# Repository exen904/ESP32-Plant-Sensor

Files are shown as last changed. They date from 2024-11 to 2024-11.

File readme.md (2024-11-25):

# ESP-32 Plant Sensor for ESP-Home and HomeAssistant

This is a simple PCB to attach 6 capacitive moisuture sensors to a ESP32 for plant monitoring in HomeAssistant. The available MiFlora and Tuya clones with Zigbee were to expensive to purchase for all of my plants, so I chose this way. 

The PCB works with both V1.2 and V2.0 sensors and applys 5V as working voltage to make it compatible with either one. Connection to the sensors is made via JST 2.0 connectors. 

## Update
PCB has been updated to accomodate larger tolerances on the ESP footprint THT holes. My first protoytpe showed no errors, but I could confirm, that the tolerances on the THT holes are extremely tight. I adjusted this in the current version, so if you did not order PCBs, please use the current version. If you ordered PCBs from the first revision, you can take a chance at drilling the holes up but I dont really recommend that, as you can also break traces during that. 

## ESP Pinout
Please refer to my KiCad Footprint of the ESP I used for the pinout, as there are so many different ESP Devkits available. 

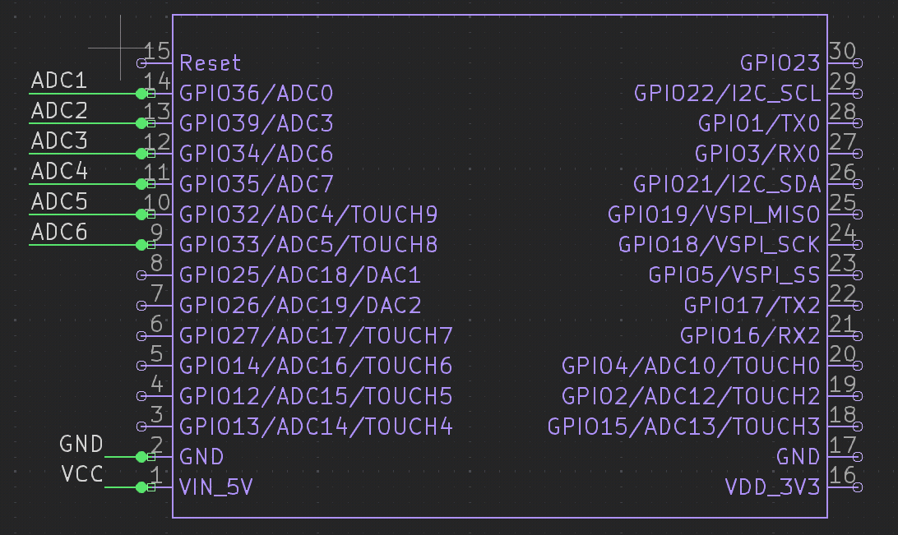
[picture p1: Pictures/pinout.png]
Pinout


## BOM
- 1x ESP32 Devkit with the correct pinout
- 6x JST B3B-XH-A (2.0mm vertical) connectors
- 4x M2x4 screws for securing the PCB in the bottom case

## Software
I run these with ESPHome, see my code in the code folder. Calibrate the values under `calibrate_linear` for each state of sensor dry and sensor 100% (sensor partly emerged underwater).

For the HomeAssistant side of things, I created a configuration.yaml entry, which ties each sensor to a plant entity. Example also linked in the code folder. Please do yourself a favour, and name your sensors in ESPHome better than I did.

## Pictures
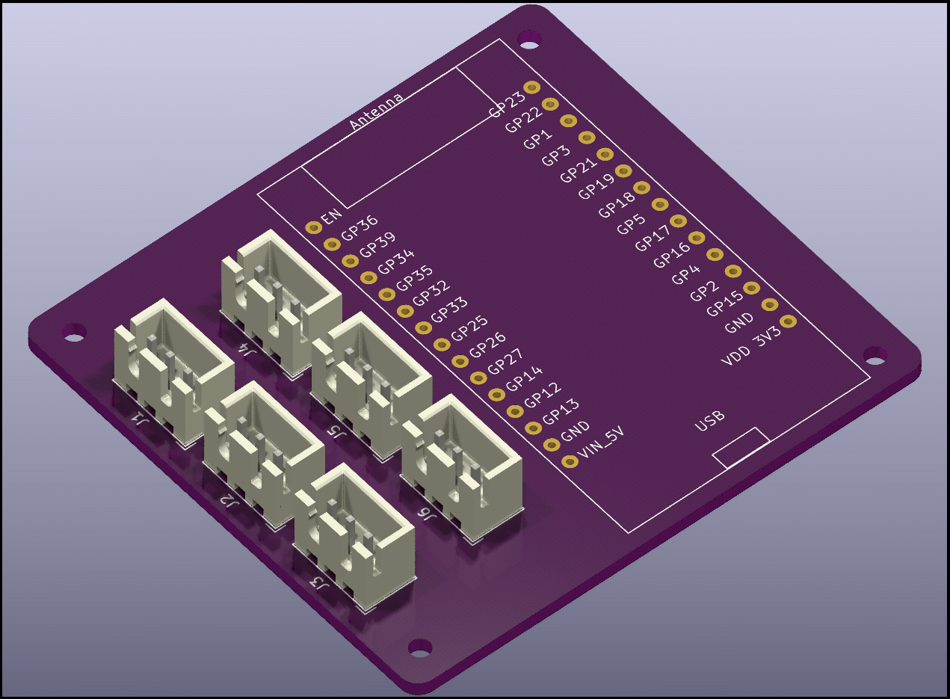
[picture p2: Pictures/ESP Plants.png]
PCB render

soldered PCB

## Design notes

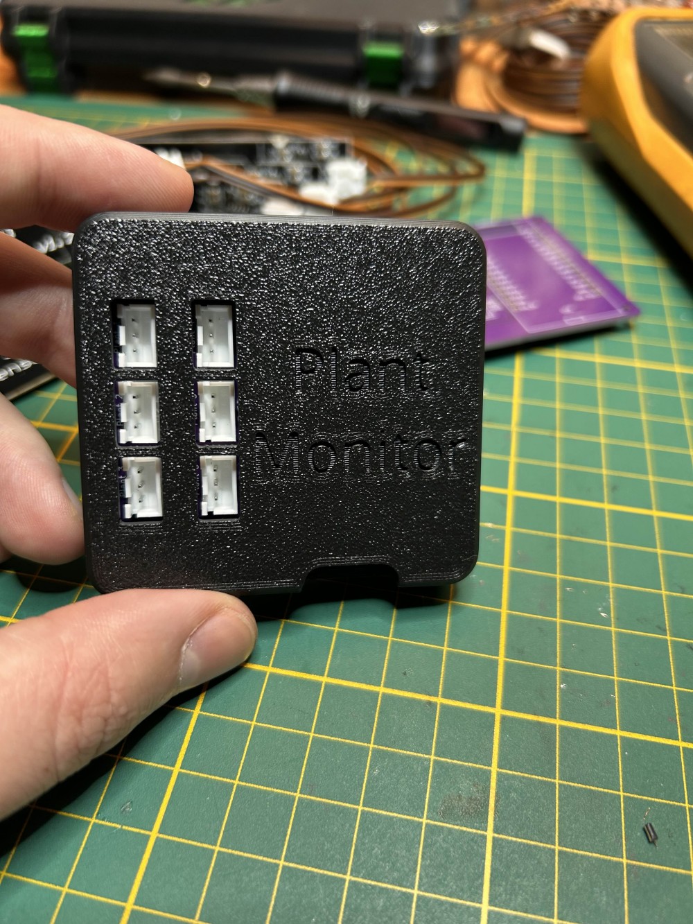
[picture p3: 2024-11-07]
Pictures/plant1.jpg

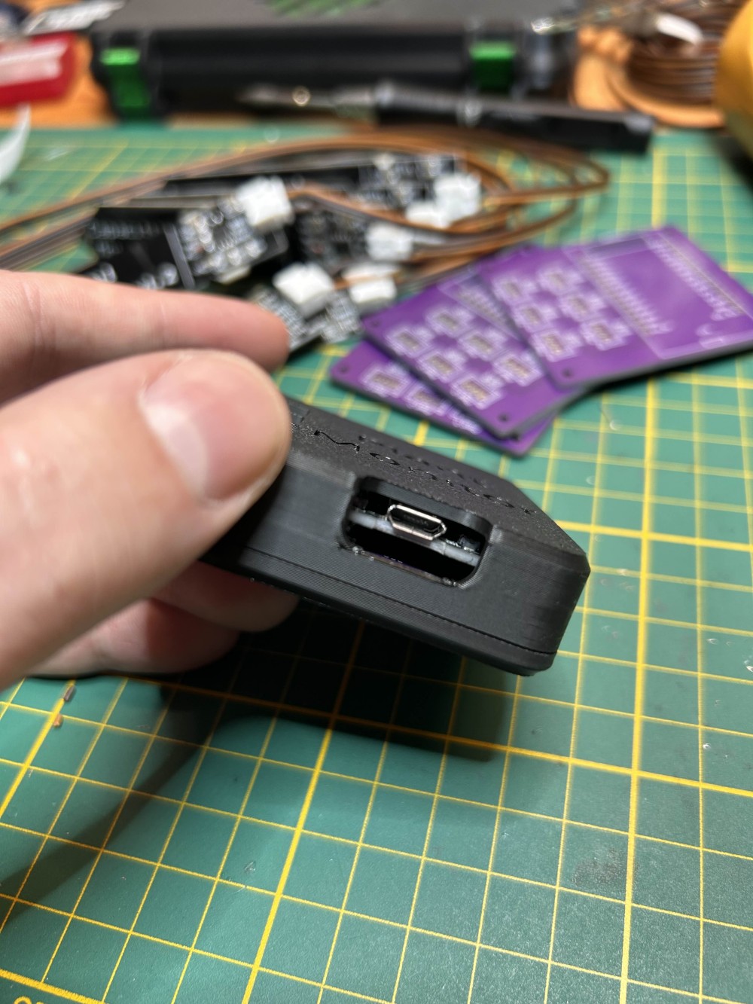
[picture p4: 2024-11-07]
Pictures/plant2.jpg

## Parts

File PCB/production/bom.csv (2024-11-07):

Designator | Footprint | Quantity | Value | LCSC Part #
NODEMCU_32S1 | ESP32_NodeMCU | 1 | ~
PLANT 1, PLANT 2, PLANT 3, PLANT 4, PLANT 5, PLANT 6 | JST_XH_B3B-XH-A_1x03_P2.50mm_Vertical | 6 | Conn_01x03_Pin

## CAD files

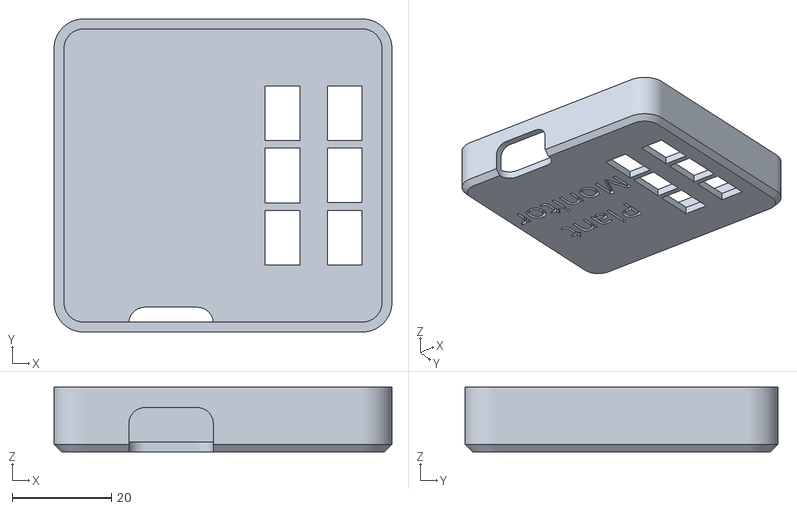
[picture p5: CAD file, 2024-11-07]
Case/Top_with_text.stl
68.0 x 63.0 x 13.0

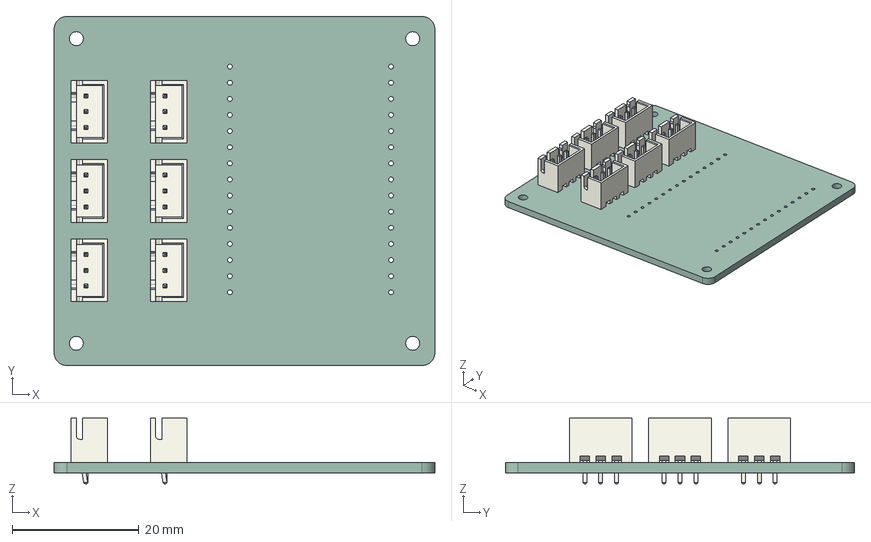
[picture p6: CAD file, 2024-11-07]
PCB/ESP Plants.step
60.0 x 55.0 x 10.4 mm
JST_B3B_XH_A x 6
_autosave-ESP Plants_PCB

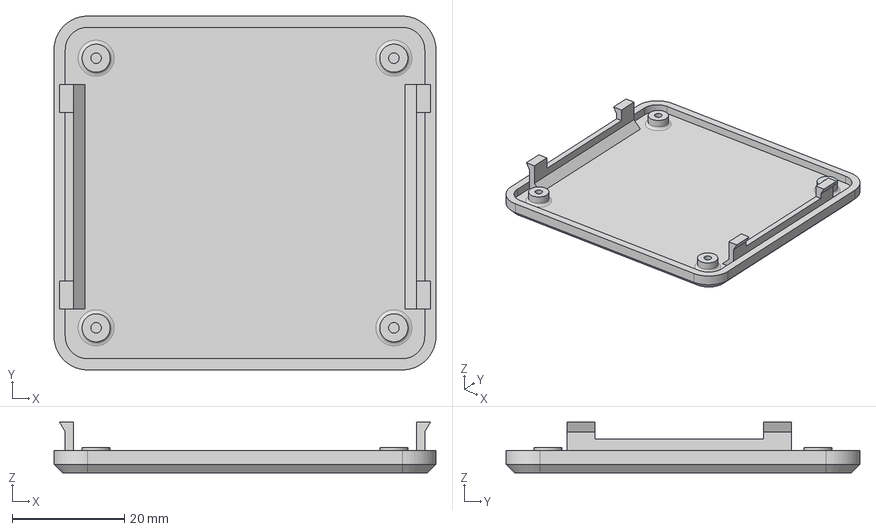
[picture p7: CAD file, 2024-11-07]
Case/Bottom.step
68.0 x 63.0 x 9.00 mm

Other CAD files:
Case/Top.step

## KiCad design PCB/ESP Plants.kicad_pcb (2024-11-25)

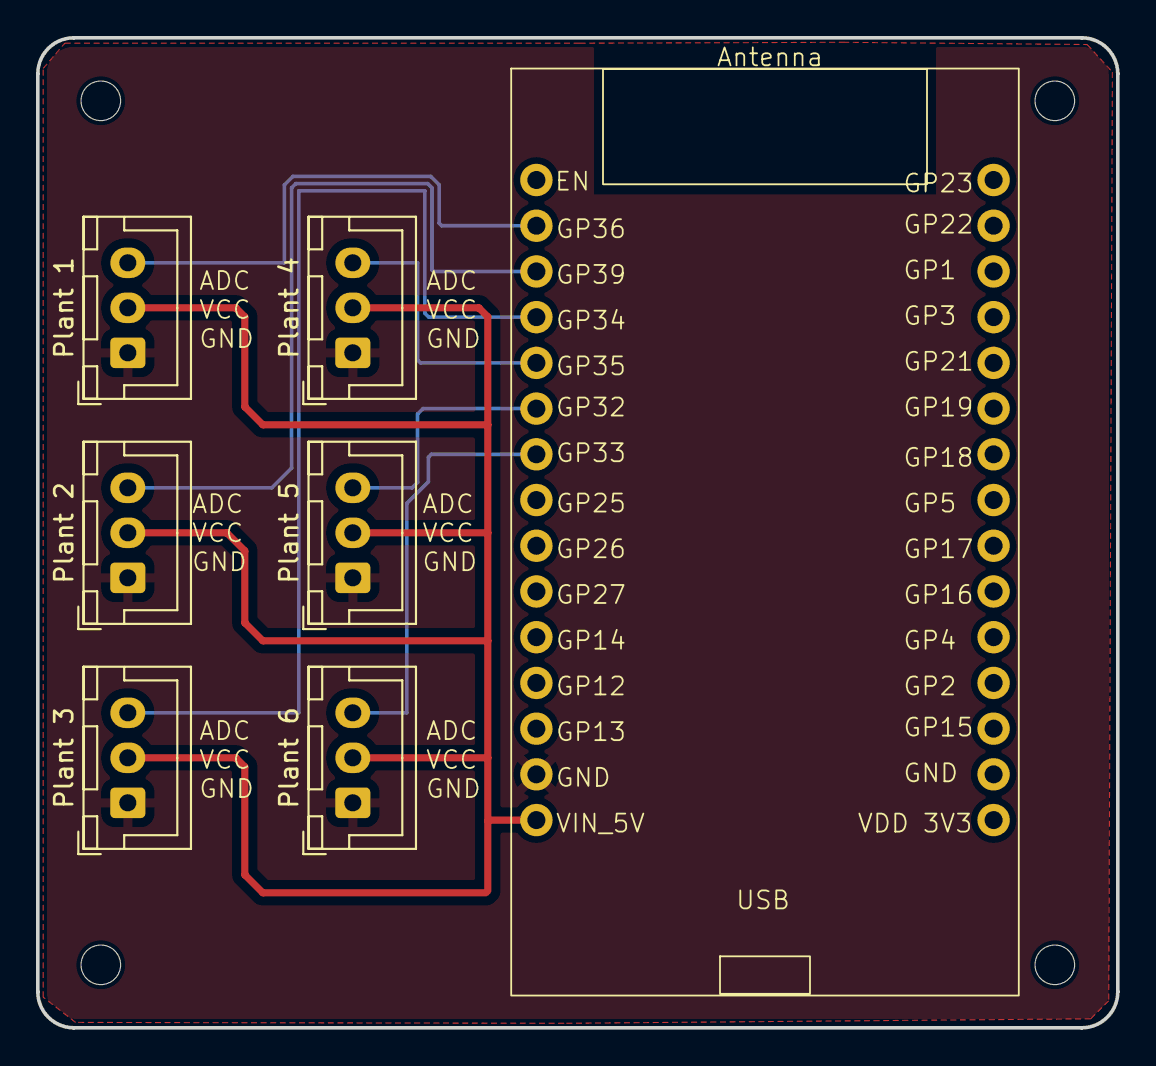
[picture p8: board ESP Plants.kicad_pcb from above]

Board: 2 copper layers, 60.0 x 55.0 mm, 7 parts (0 on the bottom side), 8 nets.

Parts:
NodeMCU_32S1: ESP32_NodeMCU
Plant 1, Plant 2, Plant 3, Plant 4, Plant 5, Plant 6: Conn_01x03_Pin; JST_XH_B3B-XH-A_1x03_P2.50mm_Vertical

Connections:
/ADC1: NodeMCU_32S1.14 (GPIO36/ADC0), Plant 1.3
/ADC2: NodeMCU_32S1.13 (GPIO39/ADC3), Plant 2.3
/ADC3: NodeMCU_32S1.12 (GPIO34/ADC6), Plant 3.3
/ADC4: NodeMCU_32S1.11 (GPIO35/ADC7), Plant 4.3
/ADC5: NodeMCU_32S1.10 (GPIO32/ADC4/TOUCH9), Plant 5.3
/ADC6: NodeMCU_32S1.9 (GPIO33/ADC5/TOUCH8), Plant 6.3
/GND: NodeMCU_32S1.2 (GND), Plant 1.1, Plant 2.1, Plant 3.1, Plant 4.1, Plant 5.1, Plant 6.1
/VCC: NodeMCU_32S1.1 (VIN_5V), Plant 1.2, Plant 2.2, Plant 3.2, Plant 4.2, Plant 5.2, Plant 6.2

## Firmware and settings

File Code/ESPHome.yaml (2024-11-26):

# your regular ESPHome configuration gets here, stuff for the sensors follows

sensor:
#Sensor 1
  - platform: adc
    attenuation: auto
    pin: GPIO036
    name: "Sensor 1"
    device_class: moisture
    update_interval: 120s
    unit_of_measurement: "%"
    filters:
    - median:
        window_size: 7
        send_every: 4
        send_first_at: 1
    - calibrate_linear:
        - 2.3 -> 0.00
        - 0.9 -> 100.00
    - lambda: if (x < 1) return 0; else return (x);
    accuracy_decimals: 0 


#Sensor 2    
  - platform: adc
    attenuation: auto
    pin: GPIO39
    name: "Sensor 2"
    device_class: moisture
    update_interval: 120s
    unit_of_measurement: "%"
    filters:
    - median:
        window_size: 7
        send_every: 4
        send_first_at: 1
    - calibrate_linear:
        - 2.3 -> 0.00
        - 0.9 -> 100.00
    - lambda: if (x < 1) return 0; else return (x);
    accuracy_decimals: 0 


#Sensor 3    
  - platform: adc
    attenuation: auto
    pin: GPIO34
    name: "Sensor 3"
    device_class: moisture
    update_interval: 120s
    unit_of_measurement: "%"
    filters:
    - median:
        window_size: 7
        send_every: 4
        send_first_at: 1
    - calibrate_linear:
        - 2.4 -> 0.00
        - 0.9 -> 100.00
    - lambda: if (x < 1) return 0; else return (x);
    accuracy_decimals: 0   
 

#Sensor 4    
  - platform: adc
    attenuation: auto
    pin: GPIO35
    name: "Sensor 4"
    device_class: moisture
    update_interval: 120s
    unit_of_measurement: "%"
    filters:
    - median:
        window_size: 7
        send_every: 4
        send_first_at: 1
    - calibrate_linear:
        - 2.4 -> 0.00
        - 0.9 -> 100.00
    - lambda: if (x < 1) return 0; else return (x);
    accuracy_decimals: 0   

#Sensor 5    
  - platform: adc
    attenuation: auto
    pin: GPIO32
    name: "Sensor 5"
    device_class: moisture
    update_interval: 120s
    unit_of_measurement: "%"
    filters:
    - median:
        window_size: 7
        send_every: 4
        send_first_at: 1
    - calibrate_linear:
        - 2.4 -> 0.00
        - 0.9 -> 100.00
    - lambda: if (x < 1) return 0; else return (x);
    accuracy_decimals: 0   

    #Sensor 6    
  - platform: adc
    attenuation: auto
    pin: GPIO33
    name: "Sensor 6"
    device_class: moisture
    update_interval: 120s
    unit_of_measurement: "%"
    filters:
    - median:
        window_size: 7
        send_every: 4
        send_first_at: 1
    - calibrate_linear:
        - 2.4 -> 0.00
        - 0.9 -> 100.00
    - lambda: if (x < 1) return 0; else return (x);
    accuracy_decimals: 0   

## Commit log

2024-11-07 added case files and updated readme
    [Bottom.step, Top.step, Top_with_text.stl]
2024-11-07 BOM updated
2024-11-25 add device class to esphome sensor
2024-11-25 THT holes on ESP footprint editet for better tolerances
    [ESP Plants.kicad_pcb]
2024-11-25 updated production files to new THT holes
2024-11-25 updated readme to current PCB revision
